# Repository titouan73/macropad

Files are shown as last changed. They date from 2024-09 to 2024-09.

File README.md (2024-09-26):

# PicoPad 
with <3 by m1tch

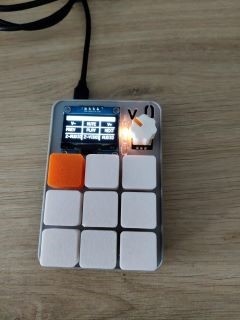
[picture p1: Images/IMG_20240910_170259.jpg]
Description de l'image

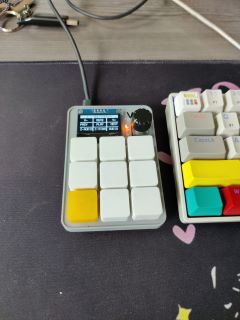
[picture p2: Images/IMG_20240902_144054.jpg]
Description de l'image


Ce projet combine un microcontrôleur utilisant **CircuitPython** avec **AutoHotkey** pour contrôler des fonctionnalités multimédia ou envoyer des émojis à l’aide de boutons physiques. En connectant plusieurs boutons à un microcontrôleur, chaque bouton peut déclencher une action, comme changer le volume, contrôler la lecture de médias ou envoyer des raccourcis clavier. Le script **AutoHotkey** intercepte ces raccourcis pour exécuter des commandes précises, comme envoyer des émojis dans vos applications.

### Matériel requis

- Un microcontrôleur compatible **CircuitPython** (Raspberry Pi Pico, Adafruit Feather, etc.).
- Des boutons physiques pour déclencher les actions.
- Un écran OLED optionnel pour afficher les pages d’actions.
- **AutoHotkey** installé sur l'ordinateur pour interpréter les combinaisons de touches envoyées.

> Pour connaitre les instructions de montage et de fabrication du PCB rdv dans le dossier Build

---

### 1. Fonctionnement du script CircuitPython

Le script CircuitPython est conçu pour :

1. **Détecter les boutons pressés** : Le script lit l'état des boutons connectés aux broches GPIO du microcontrôleur.
2. **Envoyer des raccourcis clavier** : Le microcontrôleur se comporte comme un clavier HID, envoyant des combinaisons de touches spécifiées.
3. **Basculer entre plusieurs pages d'actions** : Les boutons peuvent avoir plusieurs fonctions selon la page active, contrôlées par un encodeur rotatif.
4. **Afficher les pages sur un écran OLED** : Le microcontrôleur affiche les actions disponibles sur un écran OLED.

#### a. Initialisation des composants matériels

Les boutons, l'écran OLED et l'encodeur rotatif sont configurés dès le démarrage du script. Les boutons sont associés à des broches GPIO, tandis que l'écran OLED affiche l'état actuel (la page active et les actions disponibles).

```python
# Initialisation des boutons sur GPIO
pins = [board.GP2, board.GP3, board.GP4, board.GP5, board.GP6, board.GP7, board.GP8, board.GP9, board.GP10]
switches = [DigitalInOut(pin) for pin in pins]
for switch in switches:
    switch.direction = Direction.INPUT
    switch.pull = Pull.UP

# Initialisation de l'encodeur rotatif
encoder = rotaryio.IncrementalEncoder(board.GP18, board.GP19)
```

#### b. Gestion des pages et des actions

Le script gère plusieurs pages, chaque page étant associée à un ensemble d'actions. Par exemple, la **page multimédia** permet de contrôler le volume et la lecture, tandis qu'une autre page pourrait envoyer des raccourcis clavier spécifiques.

Les actions sont définies dans des structures comme celle-ci :

```python
page_1 = [
    [[ConsumerControlCode.VOLUME_DECREMENT], "V-", MEDIA],
    [[ConsumerControlCode.MUTE], "MUTE", MEDIA],
    [[ConsumerControlCode.VOLUME_INCREMENT], "V+", MEDIA],
    [[ConsumerControlCode.SCAN_PREVIOUS_TRACK], "PREV", MEDIA],
    [[ConsumerControlCode.PLAY_PAUSE], "PLAY", MEDIA],
    [[ConsumerControlCode.SCAN_NEXT_TRACK], "NEXT", MEDIA],
    [[Keycode.COMMAND, Keycode.LEFT_SHIFT, Keycode.A], "Z-AUDIO", KEY],
    [[Keycode.COMMAND, Keycode.LEFT_SHIFT, Keycode.V], "Z-VIDEO", KEY],
    [[Keycode.RIGHT_GUI, Keycode.RIGHT_SHIFT, Keycode.F13], "AUDIO", KEY]
]
```

Chaque action est associée à un bouton et peut être de trois types :
- **MEDIA** : Contrôles multimédia comme le volume ou la lecture.
- **KEY** : Raccourcis clavier envoyés à l'ordinateur.
- **STRING** : Texte ou émojis envoyés sous forme de chaîne.

#### c. Gestion de l’écran OLED

L'écran OLED affiche les actions disponibles pour chaque page sous forme de grille. Lorsque vous tournez l'encodeur rotatif, le script change la page active et met à jour l'affichage pour refléter les nouvelles actions.

```python
def boot_display():
    clear_screen()
    # Afficher les actions de la page active
    splash.append(ajouter_texte(page_names[current_page], 3, 20))
    splash.append(ajouter_texte(pages[current_page][0], 3, 37))
    display.root_group = splash
```

#### d. Envoi des commandes HID

Lorsqu’un bouton est pressé, le microcontrôleur envoie la commande associée en utilisant HID (Human Interface Device). Les commandes peuvent être des contrôles multimédia ou des raccourcis clavier.

```python
if keymap[button][0] == MEDIA:
    cc.send(keymap[button][1][0])  # Envoi des commandes multimédia
elif keymap[button][0] == KEY:
    kbd.press(*keymap[button][1])  # Envoi des raccourcis clavier
elif keymap[button][0] == STRING:
    layout.write("😎")  # Envoyer un émoji ou texte
```

---

### 2. Interface avec AutoHotkey

**AutoHotkey (AHK)** est utilisé pour interpréter les raccourcis clavier envoyés par le microcontrôleur. Vous pouvez utiliser AHK pour déclencher l’envoi d’émojis ou d’autres commandes en réponse à des combinaisons de touches spécifiques.

#### a. Installation d'AutoHotkey

1. Téléchargez **AutoHotkey v2** depuis [le site officiel](https://www.autohotkey.com/).
2. Créez un nouveau script AHK pour capturer les raccourcis envoyés par le microcontrôleur.
3. Vous pouvez placer un raccourci vers votre fichier AHK dans le repertoire suivant (sous windows) pour qu'il s'execute automatiquement au démarrage : `C:\Users\<user>\AppData\Roaming\Microsoft\Windows\Start Menu\Programs\Startup`

#### b. Exemple de script AutoHotkey

Le script suivant écoute les combinaisons `Ctrl + Shift + E` envoyées par le microcontrôleur et envoie des émojis à l'emplacement du curseur.

```ahk
^+e:: ; Ctrl + Shift + E
    Send "😀"  ; Envoie un smiley
return

^+v:: ; Ctrl + Shift + V
    Send "🎥"  ; Envoie un émoji caméra
return

^+a:: ; Ctrl + Shift + A
    Send "🎧"  ; Envoie un émoji casque
return
```

Dans cet exemple :
- `^+e` intercepte `Ctrl + Shift + E`.
- `Send "😀"` envoie l'émoji dans l'application active.

Vous pouvez étendre ce script en ajoutant plus de combinaisons de touches pour contrôler des actions ou insérer du texte.

---

### 3. Comment tout fonctionne ensemble

1. **Appui sur un bouton** : Vous appuyez sur un bouton physique relié au microcontrôleur.
2. **Le microcontrôleur envoie une commande HID** : Le script CircuitPython interprète l’appui et envoie une commande (comme `Ctrl + Shift + E`).
3. **AutoHotkey interprète la commande** : AHK capte la combinaison de touches et exécute une action prédéfinie, comme l'envoi d'un émoji ou d'un texte.
4. **Affichage sur l'écran OLED** : L'écran affiche les actions disponibles pour chaque page.

### Conclusion

Ce projet est un excellent exemple d'intégration entre un microcontrôleur programmable avec **CircuitPython** et l’automatisation sur PC avec **AutoHotkey**. Vous pouvez facilement personnaliser les actions des boutons pour contrôler des fonctionnalités multimédia, envoyer des émojis ou exécuter d'autres actions dans vos applications.

Le microcontrôleur se comporte comme un clavier HID, et AutoHotkey sert de pont pour interpréter ces commandes de manière flexible. Vous pouvez étendre ce projet en ajoutant des pages supplémentaires, des commandes complexes, ou en affichant des informations plus avancées sur l’écran OLED.

# Création du PCB et montage

## Matériel
- Raspberry pi PICO W
- Écran sh106 1,3"
- 9 switch MX 
- Encodeur rotatif EC11 (15mm)
- 3 resistances 10k
- Risers (min 40 pins)
- Ampoule incandescant 5V

## Assemblage

Voici les étapes d'assemblage à partir des pièces imprimées en 3d et disponibles dans le dossier 3dPrint.
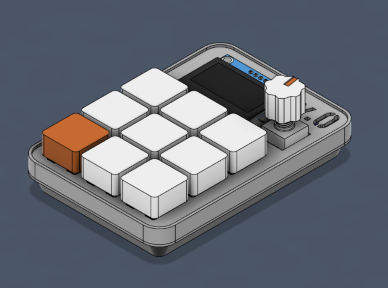
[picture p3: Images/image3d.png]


1. Souder les risers pour le RaspberryPI PICO

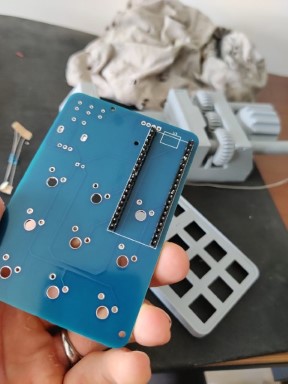
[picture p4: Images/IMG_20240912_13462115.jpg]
Description de l'image


2. Souder l'EC11 et les resistances

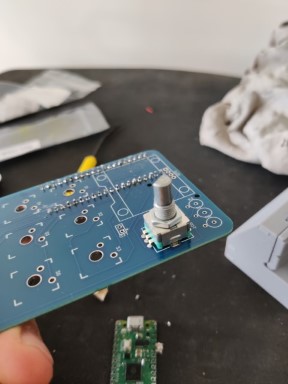
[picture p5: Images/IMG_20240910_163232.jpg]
Description de l'image

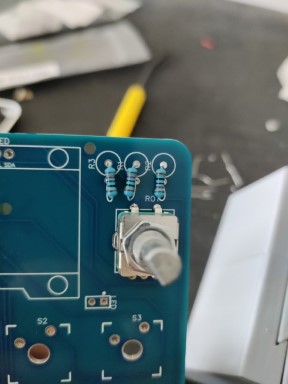
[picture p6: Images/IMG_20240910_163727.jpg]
Description de l'image


3. Clipser les switchs sur la partie haute de la case

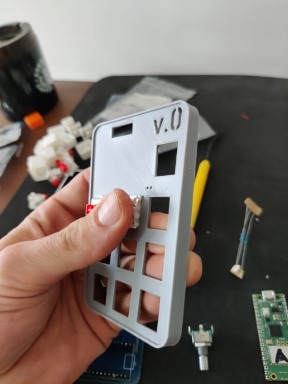
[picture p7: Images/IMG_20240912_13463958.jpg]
Description de l'image

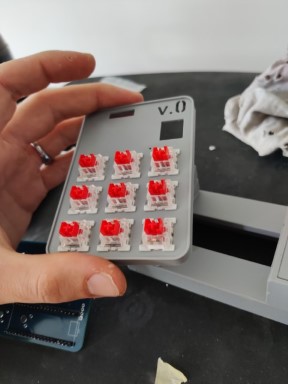
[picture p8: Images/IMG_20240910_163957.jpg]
Description de l'image


4. Placer la partie supérieur de la case et souder les switch sur le PCB

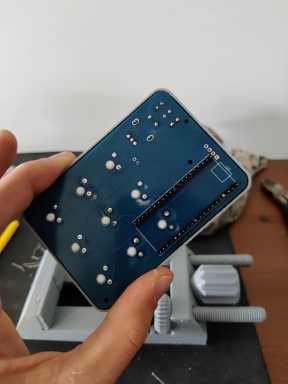
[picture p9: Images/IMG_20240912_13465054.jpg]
Description de l'image


5. Souder le raspberry pico sur le PCB

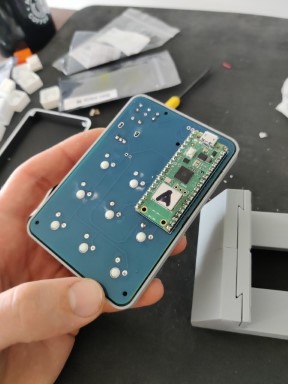
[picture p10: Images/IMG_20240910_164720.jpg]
Description de l'image


6. Souder la lampe à filament sur le PCB

Description de l'image

7. Flasher le Raspberry pico avant de refermer la case

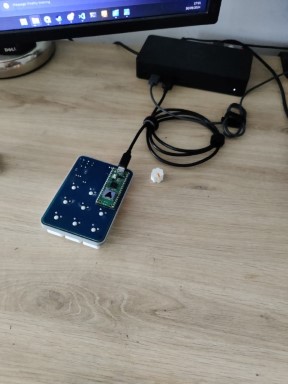
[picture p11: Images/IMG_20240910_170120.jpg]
Description de l'image


8. Refermer la case et placer les keycaps

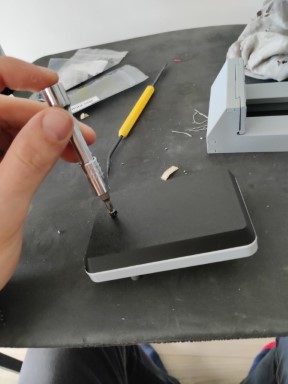
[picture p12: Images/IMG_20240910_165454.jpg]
Description de l'image

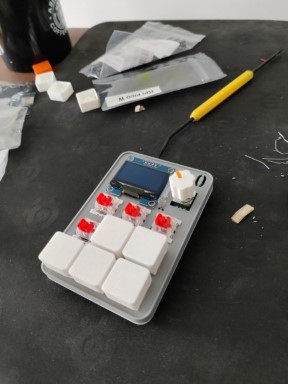
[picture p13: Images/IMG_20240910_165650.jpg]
Description de l'image


### Voilà c'est terminé ! 

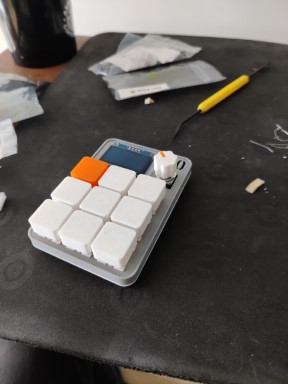
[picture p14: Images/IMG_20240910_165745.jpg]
Description de l'image


## Circuit Imprimé (PCB)

Je ne vais pas rentrer trop précisément dans les détails électroniques de la confection de ce PCB car nous sommes en bas voltages et ainsi les erreures de sont pas très graves. De plus énormément de tutoriels sont présents sur internet.

Voici les deux schémas : 
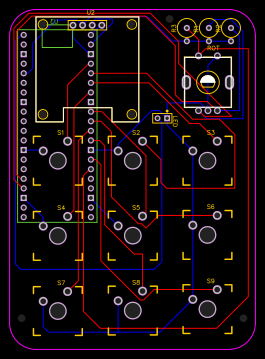
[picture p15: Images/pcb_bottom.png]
Dessous

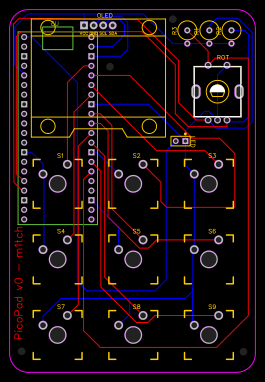
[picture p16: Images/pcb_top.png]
Dessus


Et le schéma fonctionnel : 

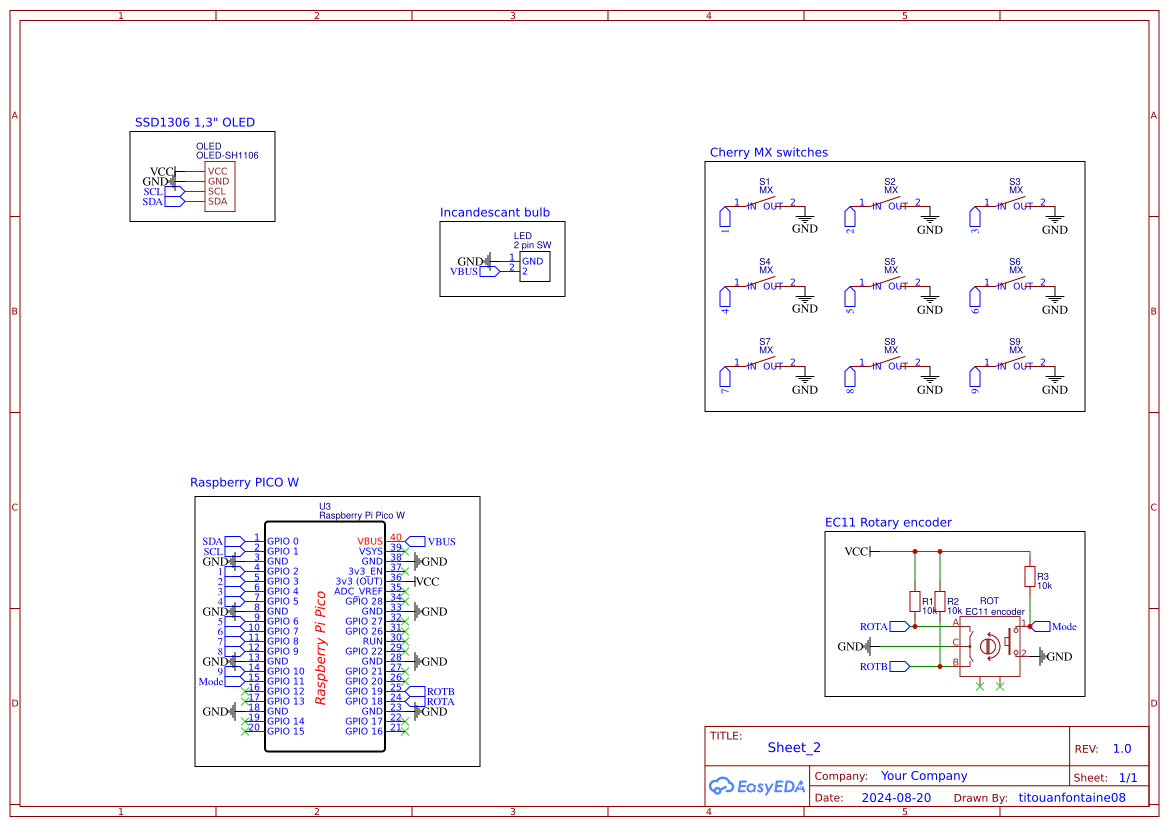
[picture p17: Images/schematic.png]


> Pour toute question vous pouvez me contacter à l'adresse titouanfontaine@hackmedaddy.fr

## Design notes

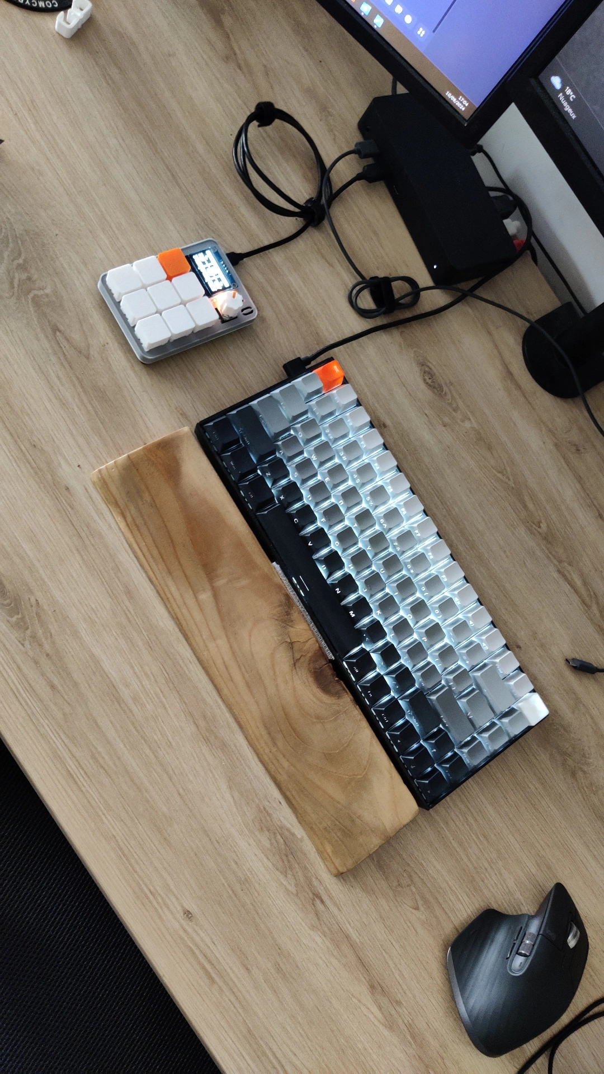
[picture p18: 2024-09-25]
Images/IMG_20240910_170420_296.bak.webp

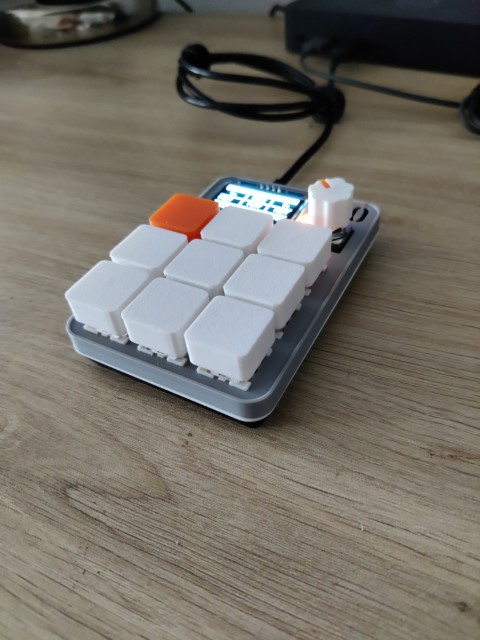
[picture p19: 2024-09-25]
Images/IMG_20240910_170255.bak.jpg

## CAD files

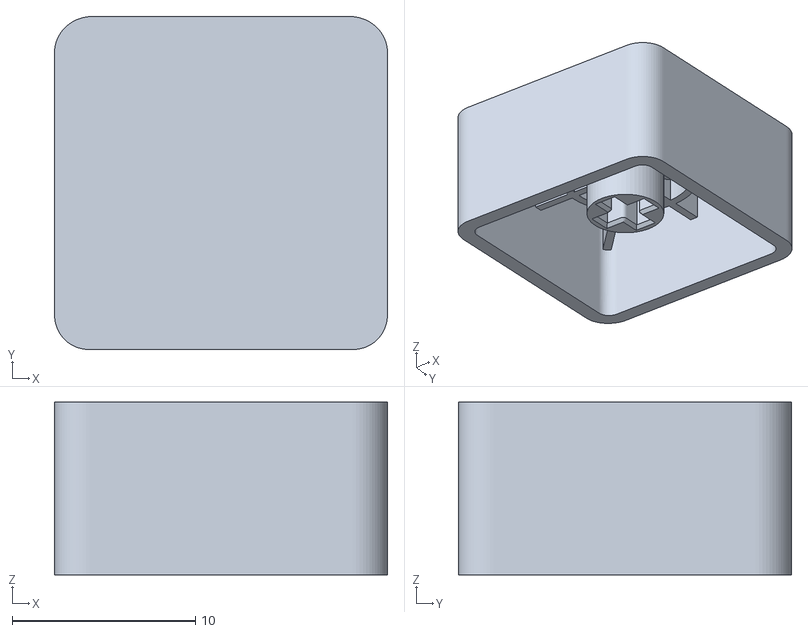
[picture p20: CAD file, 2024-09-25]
3dPrint/keycap.stl
18.1 x 18.1 x 9.41

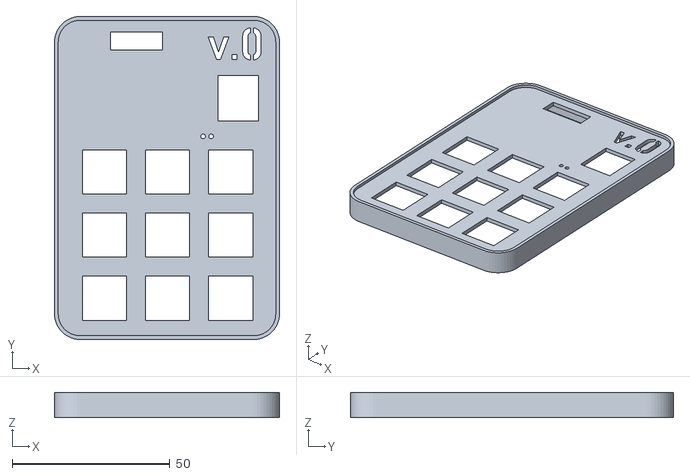
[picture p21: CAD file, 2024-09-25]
3dPrint/caseTop.stl
71.4 x 102.4 x 8.00

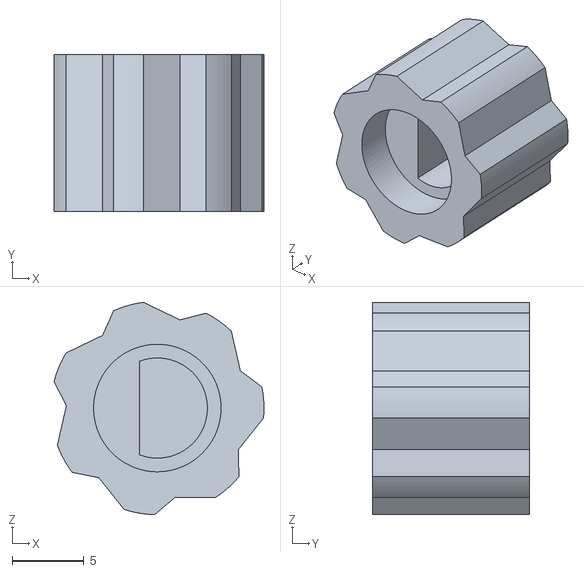
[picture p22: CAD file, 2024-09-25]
3dPrint/knobPotentiometre.stl
14.7 x 11.0 x 14.8

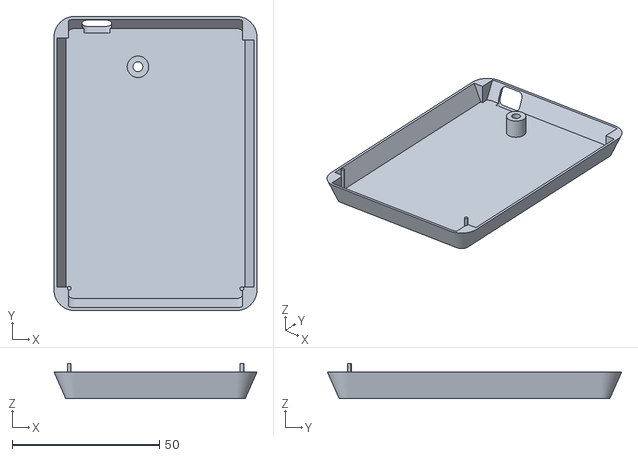
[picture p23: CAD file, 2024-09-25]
3dPrint/caseBottom.stl
69.0 x 100.0 x 12.0

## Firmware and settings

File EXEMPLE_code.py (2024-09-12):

import board
import digitalio
import time
import rotaryio
import displayio
import busio
import usb_hid
import terminalio
from digitalio import DigitalInOut, Direction, Pull
import adafruit_displayio_sh1106
from adafruit_display_text import label
from adafruit_display_shapes.rect import Rect
from adafruit_hid.consumer_control import ConsumerControl
from adafruit_hid.consumer_control_code import ConsumerControlCode
from adafruit_hid.keyboard import Keyboard
from adafruit_hid.keycode import Keycode
from adafruit_hid.keyboard_layout_us import KeyboardLayoutUS


## VARIABLES ## 

# Initialisation des variables de page
current_page = 0


MEDIA = 1
KEY = 2
STRING = 3

kbd = Keyboard(usb_hid.devices)
cc = ConsumerControl(usb_hid.devices)
layout = KeyboardLayoutUS(kbd)

# Initialisation de l'encodeur rotatif
#Bouton EC11
buttonEC11 = digitalio.DigitalInOut(board.GP11)
buttonEC11.direction = digitalio.Direction.INPUT
buttonEC11.pull = digitalio.Pull.UP  # Utilise la résistance pull-down intégrée
encoder = rotaryio.IncrementalEncoder(board.GP19, board.GP18)
last_position = 0

# macro keys GPIO Pins
pins = [
    board.GP2,
    board.GP3,
    board.GP4,
    board.GP5,
    board.GP6,
    board.GP7,
    board.GP8,
    board.GP9,
    board.GP10,
]


switches = [0, 1, 2, 3, 4, 5, 6, 7, 8]

for i in range(9):
    switches[i] = DigitalInOut(pins[i])
    switches[i].direction = Direction.INPUT
    switches[i].pull = Pull.UP

switch_state = [0, 0, 0, 0, 0, 0, 0, 0, 0]

# Création de l'objet HID pour les contrôles consommateurs
cc = ConsumerControl(usb_hid.devices)

# Intégration de la LED pas utilisé mais si vous voulez jouer avec elle est initialisée
led = digitalio.DigitalInOut(board.LED)
led.direction = digitalio.Direction.OUTPUT

# Libère les affichages actuels (si nécessaire)
displayio.release_displays()

# Initialisation de l'I2C et de l'écran SH1106
i2c = busio.I2C(scl=board.GP1, sda=board.GP0)
display_bus = displayio.I2CDisplay(i2c, device_address=0x3C)
display = adafruit_displayio_sh1106.SH1106(display_bus, width=132, height=64)

# Crée le splash pour contenir les éléments d'affichage
splash = displayio.Group()

# Dimensions de l'écran
screen_width = display.width
screen_height = display.height


## FONCTIONS ##

# Fonction pour ajouter du texte à l'écran
def ajouter_texte(texte, x, y, taille=1, text_color=0xFFFFFF  ):
    return label.Label(terminalio.FONT, text=texte, color=text_color, scale=taille, x=x, y=y)

# Fonction pour effacer tout l'écran
def clear_screen():
    while len(splash) > 0:
        splash.pop()

# Fonction pour centrer le texte horizontalement
def centrer_texte(texte, largeur_ecran):
    largeur_texte = len(texte) * 6  # 6 pixels par caractère avec terminalio.FONT
    x = (largeur_ecran - largeur_texte) // 2
    return x

#savoir si l'encodeur rotatif va a gauche ou a droite
def left_or_right(position, last_position):
    if position > last_position:
        return "right"
    elif position < last_position:
        return "left"
    return None

# Fonction pour initialiser l'écran et afficher une matrice de titres
def boot_display():
    global current_page
    clear_screen()
    x_centre_titre = centrer_texte(page_names[current_page], display.width)
    
    # Laisser une ligne de titre
    title_height = 11
    usable_height = screen_height - title_height

    # Dimensions de chaque case
    num_rows = 3
    num_cols = 3
    cell_width = screen_width // num_cols  # Largeur de chaque case
    cell_height = usable_height // num_rows  # Hauteur de chaque case
    spacing = 2  # Pas d'espace entre les cases pour remplir toute la largeur et la hauteur

    # Crée les cases et les espacements
    for row in range(num_rows):
        for col in range(num_cols):
            # Calcule la position de chaque case
            x = col * (cell_width + spacing)
            y = title_height + row * (cell_height + spacing)
            # Dessine l'espace blanc autour des cases
            if col < num_cols - 1:  # Espace à droite des cases
                spacer = Rect(x=x + cell_width, y=y, width=spacing, height=cell_height, fill=0xFFFFFF)
                splash.append(spacer)
            if row < num_rows - 1:  # Espace en dessous des cases
                spacer = Rect(x=x, y=y + cell_height, width=cell_width + spacing, height=spacing, fill=0xFFFFFF)
                splash.append(spacer)

    # Dessiner le fond blanc pour le titre
    title_bg = Rect(x=0, y=0, width=screen_width, height=title_height, fill=0xFFFFFF)
    splash.append(title_bg)

    # Dessiner le texte du titre en noir
    x_centre_titre = centrer_texte(page_names[current_page], display.width)
    splash.append(ajouter_texte(page_names[current_page], x_centre_titre, 5,1,0x000000))  # 2 pixels de marge du haut
    splash.append(ajouter_texte(pages[current_page][0], 3, 20))
    splash.append(ajouter_texte(pages[current_page][1], 3, 37))
    splash.append(ajouter_texte(pages[current_page][2], 3, 56))


    # Ajoute le splash au display pour l'affichage
    display.root_group = splash


def assignKeyMap():
    return {
        (0): (pages_object[current_page][0][2], pages_object[current_page][0][0]),
        (1): (pages_object[current_page][1][2], pages_object[current_page][1][0]),
        (2): (pages_object[current_page][2][2], pages_object[current_page][2][0]),
        (3): (pages_object[current_page][3][2], pages_object[current_page][3][0]),
        (4): (pages_object[current_page][4][2], pages_object[current_page][4][0]),
        (5): (pages_object[current_page][5][2], pages_object[current_page][5][0]),
        (6): (pages_object[current_page][6][2], pages_object[current_page][6][0]),
        (7): (pages_object[current_page][7][2], pages_object[current_page][7][0]),
        (8): (pages_object[current_page][8][2], pages_object[current_page][8][0])
    }



## PAGES ##
# MULTI-MEDIA
page_1 = [
    
    [[ConsumerControlCode.VOLUME_DECREMENT], "V-",MEDIA],
    [[ConsumerControlCode.MUTE], "MUTE",MEDIA],
    [[ConsumerControlCode.VOLUME_INCREMENT], "V+",MEDIA],
    [[ConsumerControlCode.SCAN_PREVIOUS_TRACK], "PREV", MEDIA],
    [[ConsumerControlCode.PLAY_PAUSE], "PLAY", MEDIA],
    [[ConsumerControlCode.SCAN_NEXT_TRACK], "NEXT", MEDIA],
    [[Keycode.COMMAND, Keycode.LEFT_SHIFT, Keycode.A], "Z-AUDIO" ,KEY],
    [[Keycode.COMMAND, Keycode.LEFT_SHIFT, Keycode.V], "Z-VIDEO",KEY],
    [[Keycode.RIGHT_GUI, Keycode.RIGHT_SHIFT, Keycode.F13], "AUDIO",KEY],
]

page_1_format = [
    f"  {page_1[0][1]}     {page_1[1][1]}     {page_1[2][1]}",
    f"{page_1[3][1]}     {page_1[4][1]}    {page_1[5][1]}",
    f"{page_1[6][1]} {page_1[7][1]} {page_1[8][1]}"
]

#Emojis
page_2 = [
    [[Keycode.CONTROL, Keycode.WINDOWS, Keycode.A], "joy",KEY],
    [[Keycode.CONTROL, Keycode.WINDOWS, Keycode.B], "monkey",KEY],
    [[Keycode.CONTROL, Keycode.WINDOWS, Keycode.C], "smirk",KEY],
    [[Keycode.CONTROL, Keycode.WINDOWS, Keycode.D], "love",KEY],
    [[Keycode.CONTROL, Keycode.WINDOWS, Keycode.E], "sad",KEY],
    [[Keycode.CONTROL, Keycode.WINDOWS, Keycode.F], "o.o",KEY],
    [[Keycode.CONTROL, Keycode.WINDOWS, Keycode.G], "blazé",KEY],
    [[Keycode.CONTROL, Keycode.WINDOWS, Keycode.H], "cry",KEY],
    [[Keycode.CONTROL, Keycode.WINDOWS, Keycode.I], "géné",KEY],
]

page_2_format = [
    f"{page_2[0][1]}     {page_2[1][1]}  {page_2[2][1]}",
    f"{page_2[3][1]}     {page_2[4][1]}    {page_2[5][1]}",
    f"{page_2[6][1]}   {page_2[7][1]}     {page_2[8][1]}",
]


#Page pour tester les switchs
page_3 = [
    [[u'sw1'], "sw1",STRING],
    [[u'sw2'], "sw2",STRING],
    [[u'sw3'], "sw3",STRING],
    [[u'sw4'], "sw4",STRING],
    [[u'sw5'], "sw5",STRING],
    [[u'sw6'], "sw6",STRING],
    [[u'sw7'], "sw7",STRING],
    [[u'sw8'], "sw8",STRING],
    [[u'sw9'], "sw9",STRING]
    
]

page_3_format = [
    f"{page_3[0][1]}       {page_3[1][1]}     {page_3[2][1]}",
    f"{page_3[3][1]}      {page_3[4][1]}      {page_3[5][1]}",
    f"{page_3[6][1]}      {page_3[7][1]}      {page_3[8][1]}",
]

#Emojis ASCII
page_4 = [
    [[Keycode.CONTROL, Keycode.WINDOWS, Keycode.J], "abaa",KEY], #¯\_(ツ)_/¯
    [[Keycode.CONTROL, Keycode.WINDOWS, Keycode.K], "shoot",KEY], #( -_•)▄︻テحكـ━
    [[Keycode.CONTROL, Keycode.WINDOWS, Keycode.L], "smirk",KEY], #( ͡° ͜ʖ ͡°)
    [[Keycode.CONTROL, Keycode.WINDOWS, Keycode.M], "flpTbl",KEY], #(╯°□°）╯︵ ┻━┻
    [[Keycode.CONTROL, Keycode.WINDOWS, Keycode.N], "angry",KEY], #ᕦ(ò_óˇ)ᕤ
    [[Keycode.CONTROL, Keycode.WINDOWS, Keycode.O], "o.o",KEY], #(⊙ _ ⊙ )
    [[Keycode.CONTROL, Keycode.WINDOWS, Keycode.P], "uWu",KEY],
    [[Keycode.CONTROL, Keycode.WINDOWS, Keycode.Q], "fr",KEY],
    [[Keycode.CONTROL, Keycode.WINDOWS, Keycode.R], "Russe",KEY], #если ты можешь это прочитать, то ты дерьмо
]
    


page_4_format = [
    f"{page_4[0][1]}     {page_4[1][1]}  {page_4[2][1]}",
    f"{page_4[3][1]}  {page_4[4][1]}    {page_4[5][1]}",
    f"{page_4[6][1]}       {page_4[7][1]}    {page_4[8][1]}",
]

pages = [page_1_format, page_2_format, page_3_format, page_4_format]
page_names = ["1 - MULTIMEDIA", "2 - EMOJI", "3 - TEST", "4 - CS2"]
pages_object = [page_1, page_2, page_3, page_4]

keymap = {
    (0): (pages_object[current_page][0][2], pages_object[current_page][0][0]),
    (1): (pages_object[current_page][1][2], pages_object[current_page][1][0]),
    (2): (pages_object[current_page][2][2], pages_object[current_page][2][0]),
    (3): (pages_object[current_page][3][2], pages_object[current_page][3][0]),
    (4): (pages_object[current_page][4][2], pages_object[current_page][4][0]),
    (5): (pages_object[current_page][5][2], pages_object[current_page][5][0]),
    (6): (pages_object[current_page][6][2], pages_object[current_page][6][0]),
    (7): (pages_object[current_page][7][2], pages_object[current_page][7][0]),
    (8): (pages_object[current_page][8][2], pages_object[current_page][8][0])
}

# Affichage de la matrice de titre lors du démarrage
boot_display()


## BOUCLE D'EXECUTION ##
while True:
    position = encoder.position
    comparison = left_or_right(position, last_position)
    if comparison:
        if comparison == "right" and current_page < len(pages)-1:
            current_page = current_page + 1
            keymap = assignKeyMap()
            boot_display()
        elif comparison == "left" and current_page != 0:
            current_page = current_page - 1
            keymap = assignKeyMap()
            boot_display()
    last_position = position

    #Mute sur chaque page avec le click de l'EC11
    if not buttonEC11.value:
        cc.send(ConsumerControlCode.MUTE)
        time.sleep(0.5)


    for button in range(9):
        if switch_state[button] == 0:
            if not switches[button].value:
                print("pressed")
                try:
                    if keymap[button][0] == KEY:
                        kbd.press(*keymap[button][1])
                        print(*keymap[button][1])
                    elif keymap[button][0] == STRING:
                        for letter in keymap[button][1][0]:
                            layout.write(letter)
                    else:
                        cc.send(keymap[button][1][0])
                except ValueError:  # deals w six key limit
                    pass
                switch_state[button] = 1

        if switch_state[button] == 1:
            if switches[button].value:
                try:
                    if keymap[button][0] == KEY:
                        kbd.release(*keymap[button][1])
                except ValueError:
                    pass
                switch_state[button] = 0


 # type: ignore

 

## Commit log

2024-09-12 Ajout du fichier readme.md et mise en gitignore du dossier pico
2024-09-12 Ajout des codes EXEMPLES
2024-09-12 Suppression de mon fichier ahk perso
2024-09-26 suppression de l'ancien README_BUILD
